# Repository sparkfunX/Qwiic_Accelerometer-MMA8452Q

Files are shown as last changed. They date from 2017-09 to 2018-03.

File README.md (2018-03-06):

View this project on [CADLAB.io](https://cadlab.io/node/733). 

Qwiic Accelerometer - MMA8452Q
========================================

Qwiic Accelerometer - MMA8452Q

[*SPX-14248*](https://www.sparkfun.com/products/14248)

The Qwiic Accelerometer makes it extremely easy to get playing with tilt, acceleration, and movement sensing. Plug a [Qwiic Shield](https://www.sparkfun.com/search/results?term=qwiic) onto your platform of choice, plug the Qwiic Accelerometer onto the shield and start sensing! 

The Qwiic Accelerometer - MMA8452Q is a smart low-power, three-axis, MEMS accelerometer with 12 bits of resolution. This accelerometer is packed with embedded functions with flexible user programmable options, configurable to two interrupt pins. Embedded interrupt functions allow for overall power savings relieving the host processor from continuously polling data.

The MMA8452Q has user selectable full scales of ±2g/±4g/±8g with high pass filtered data as well as non filtered data available real-time. The device can be configured to generate inertial wake-up interrupt signals from any combination of the configurable embedded functions allowing the MMA8452Q to monitor events and remain in a low power mode during periods of inactivity.

The [Qwiic system](http://www.sparkfun.com/qwiic) enables fast and solderless connection between popular platforms and various sensors and actuators. You can read more about the Qwiic system [here](http://www.sparkfun.com/qwiic). 

License Information
-------------------

This product is _**open source**_!

Please review the LICENSE.md file for license information.

If you have any questions or concerns on licensing, please contact techsupport@sparkfun.com.

Distributed as-is; no warranty is given.

- Your friends at SparkFun.

_<COLLABORATION CREDIT>_

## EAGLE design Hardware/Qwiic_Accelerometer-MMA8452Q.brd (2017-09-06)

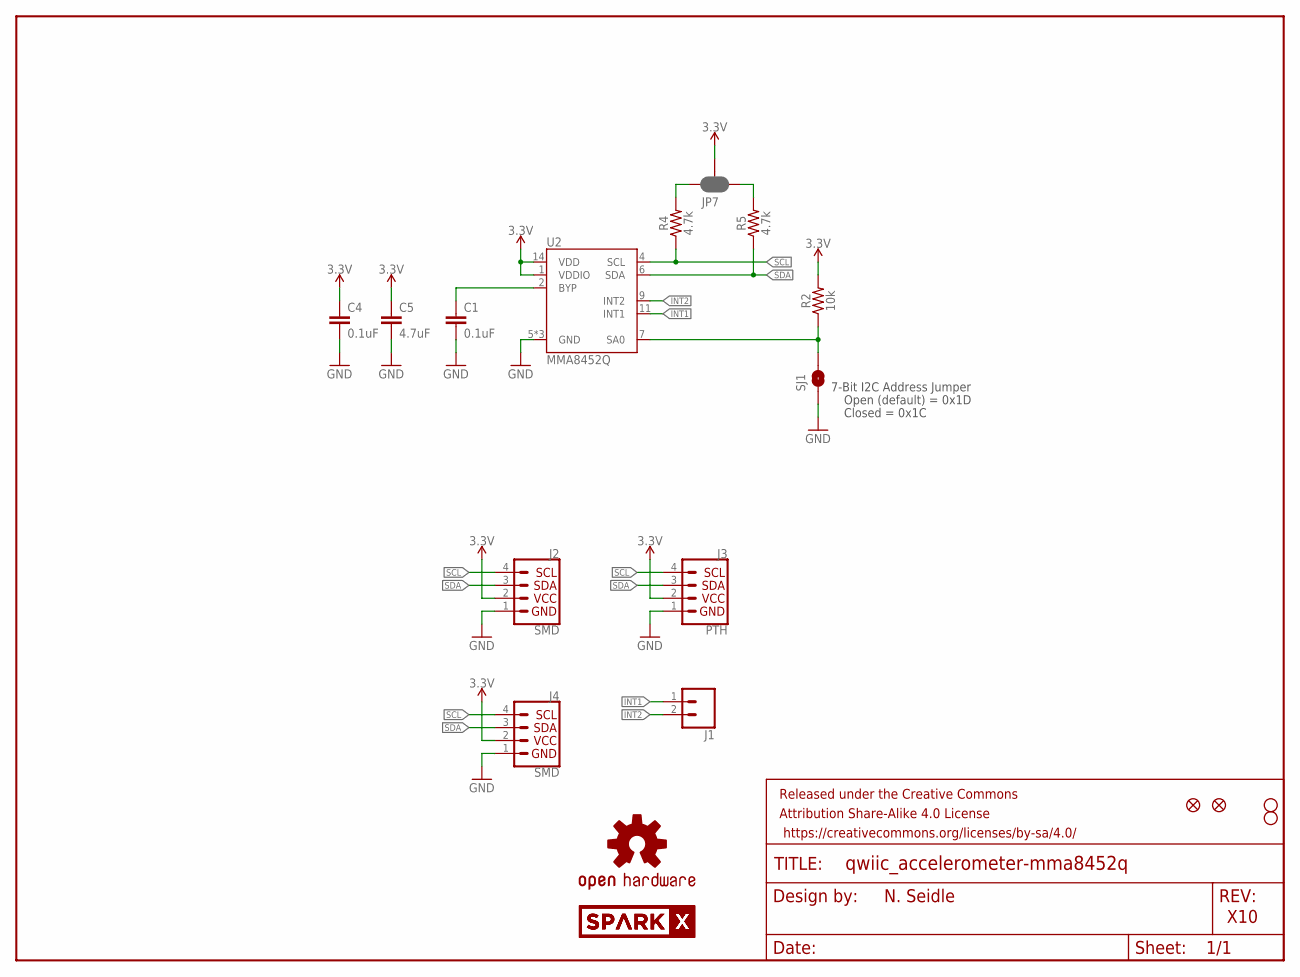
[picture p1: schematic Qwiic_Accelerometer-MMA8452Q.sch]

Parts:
C1, C4: 0.1uF; 0603
C5: 4.7uF; 0603
FRAME1: FRAME-LETTER; CREATIVE_COMMONS
J1: CONN_021X02_NO_SILK; 1X02_NO_SILK
J2, J4: SMD; 1X04_1MM_RA
J3: PTH; 1X04_NO_SILK
JP2, JP6: FIDUCIALUFIDUCIAL; MICRO-FIDUCIAL
JP3, JP4: STAND-OFF
JP7: JUMPER-SMT_3_2-NC_PASTE_SILK; SMT-JUMPER_3_2-NC_PASTE_SILK
LOGO1: OSHW-LOGOMINI; OSHW-LOGO-MINI
R2: 10k; 0603
R4, R5: 4.7k; 0603
SJ1: SOLDERJUMPERNO; SJ_2S-NO
U2: MMA8452Q; QFN-16_0.5MM
U$1, U$2: SPARKX-LOGO4; SPARKX-MEDIUM

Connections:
3.3V: C4.1, C5.1, J2.2 (VCC), J3.2 (VCC), J4.2 (VCC), JP7.2, R2.2, U2.1 (VDDIO), U2.14 (VDD)
BYP: C1.1, U2.2 (BYP)
GND: C1.2, C4.2, C5.2, J2.1 (GND), J3.1 (GND), J4.1 (GND), SJ1.1, U2.5 (GND), U2.10 (GND), U2.12 (GND)
INT1: J1.1, U2.11 (INT1)
INT2: J1.2, U2.9 (INT2)
unnamed: JP7.1, R5.2
unnamed: JP7.3, R4.2
SA0: R2.1, SJ1.2, U2.7 (SA0)
SCL: J2.4 (SCL), J3.4 (SCL), J4.4 (SCL), R4.1, U2.4 (SCL)
SDA: J2.3 (SDA), J3.3 (SDA), J4.3 (SDA), R5.1, U2.6 (SDA)

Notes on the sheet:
7-Bit I2C Address Jumper
Closed = 0x1C
Open (default) = 0x1D
N. Seidle
X10

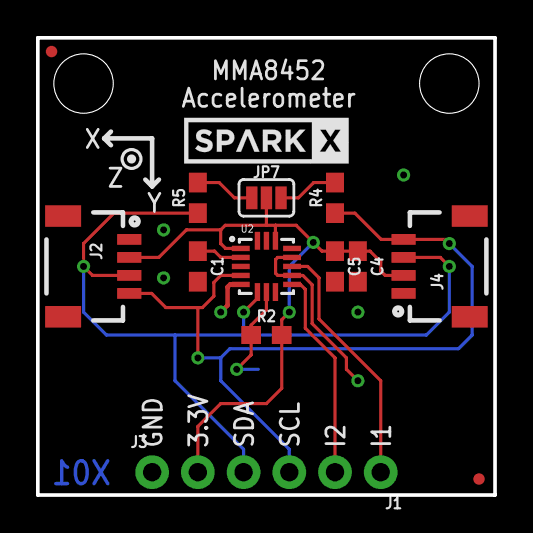
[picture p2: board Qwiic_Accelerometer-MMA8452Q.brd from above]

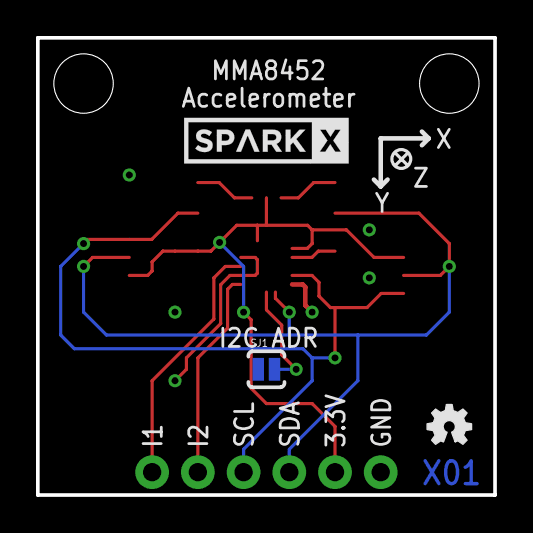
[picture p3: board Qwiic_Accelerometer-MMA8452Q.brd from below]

Board: 2 copper layers, 25.4 x 25.4 mm, 21 parts (3 on the bottom side), 10 nets.

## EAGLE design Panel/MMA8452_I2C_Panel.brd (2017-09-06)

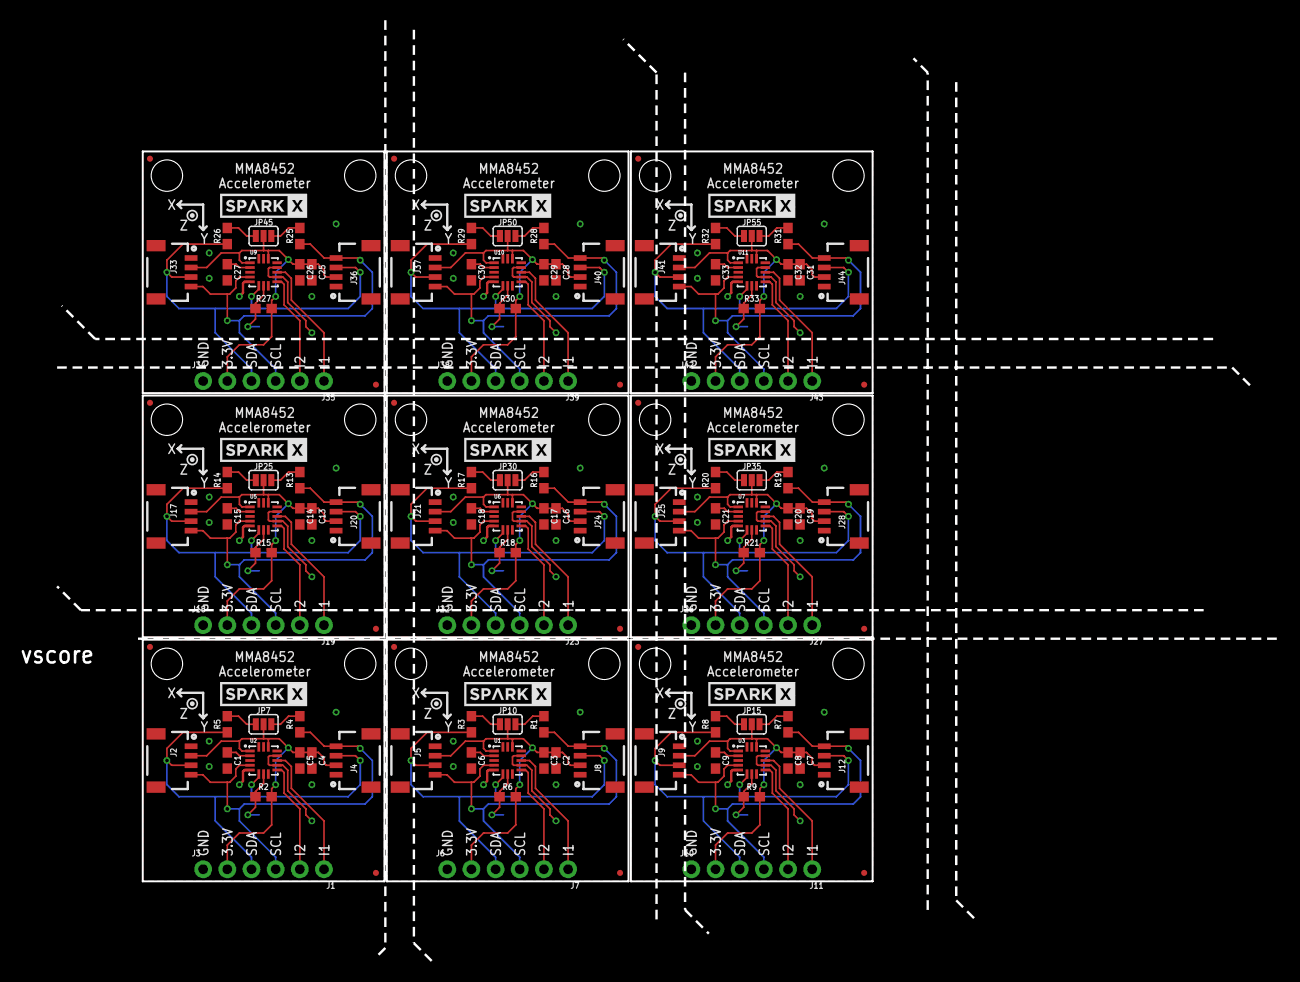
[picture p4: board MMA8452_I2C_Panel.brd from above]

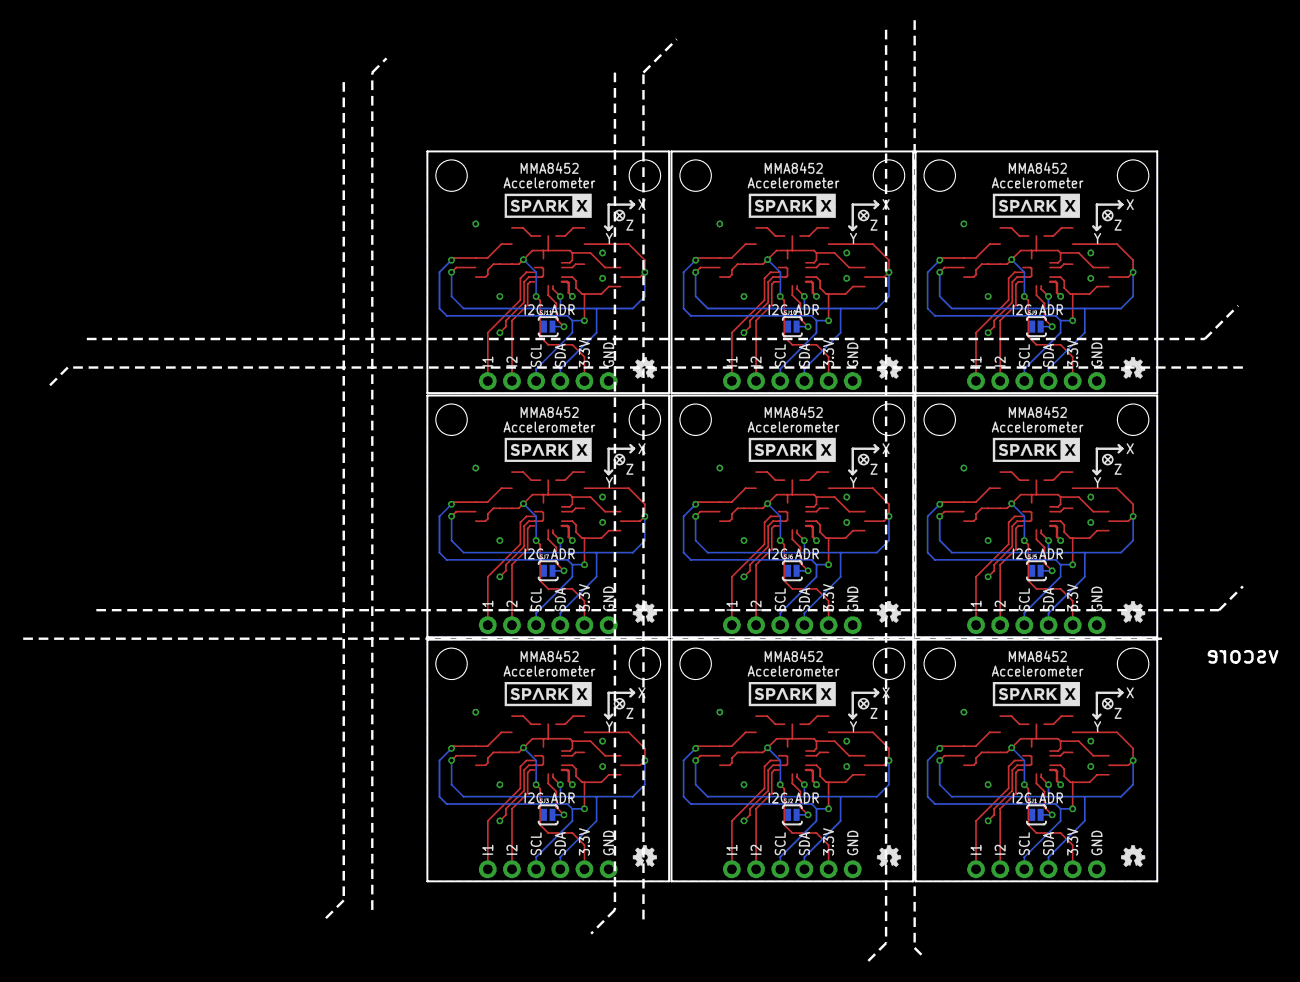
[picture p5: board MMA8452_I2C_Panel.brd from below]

Board: 2 copper layers, 128.5 x 99.0 mm, 180 parts (27 on the bottom side), 90 nets.

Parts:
C1, C2, C4, C6, C7, C9, C13, C15, C16, C18, C19, C21, C25, C27, C28, C30, C31, C33: 0.1uF; 0603
C3, C5, C8, C14, C17, C20, C26, C29, C32: 4.7uF; 0603
J1, J7, J11, J19, J23, J27, J35, J39, J43: 1X02_NO_SILK
J2, J4, J5, J8, J9, J12, J17, J20, J21, J24, J25, J28, J33, J36, J37, J40, J41, J44: SMD; 1X04_1MM_RA
J3, J6, J10, J18, J22, J26, J34, J38, J42: PTH; 1X04_NO_SILK
JP1, JP3, JP4, JP5, JP11, JP12, JP21, JP22, JP26, JP27, JP31, JP32, JP41, JP42, JP46, JP47, JP51, JP52: STAND-OFF
JP2, JP6, JP8, JP9, JP13, JP14, JP23, JP24, JP28, JP29, JP33, JP34, JP43, JP44, JP48, JP49, JP53, JP54: FIDUCIALUFIDUCIAL; MICRO-FIDUCIAL
JP7, JP10, JP15, JP25, JP30, JP35, JP45, JP50, JP55: SMT-JUMPER_3_2-NC_PASTE_SILK
LOGO1, LOGO2, LOGO3, LOGO5, LOGO6, LOGO7, LOGO9, LOGO10, LOGO11: OSHW-LOGOMINI; OSHW-LOGO-MINI
R1, R3, R4, R5, R7, R8, R13, R14, R16, R17, R19, R20, R25, R26, R28, R29, R31, R32: 4.7k; 0603
R2, R6, R9, R15, R18, R21, R27, R30, R33: 10k; 0603
SJ1, SJ2, SJ3, SJ5, SJ6, SJ7, SJ9, SJ10, SJ11: SJ_2S-NO
U1, U2, U3, U5, U6, U7, U9, U10, U11: MMA8452Q; QFN-16_0.5MM
U$1, U$2, U$3, U$4, U$5, U$6, U$9, U$10, U$11, U$12, U$13, U$14, U$17, U$18, U$19, U$20, U$21, U$22: SPARKX-LOGO4; SPARKX-MEDIUM

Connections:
3.3V: C4.1, C5.1, J2.2, J3.2, J4.2, JP7.2, R2.2, U2.1, U2.14
3.3V1: C2.1, C3.1, J5.2, J6.2, J8.2, JP10.2, R6.2, U1.1, U1.14
3.3V2: C7.1, C8.1, J9.2, J10.2, J12.2, JP15.2, R9.2, U3.1, U3.14
3.3V4: C13.1, C14.1, J17.2, J18.2, J20.2, JP25.2, R15.2, U5.1, U5.14
3.3V5: C16.1, C17.1, J21.2, J22.2, J24.2, JP30.2, R18.2, U6.1, U6.14
3.3V6: C19.1, C20.1, J25.2, J26.2, J28.2, JP35.2, R21.2, U7.1, U7.14
3.3V8: C25.1, C26.1, J33.2, J34.2, J36.2, JP45.2, R27.2, U9.1, U9.14
3.3V9: C28.1, C29.1, J37.2, J38.2, J40.2, JP50.2, R30.2, U10.1, U10.14
3.3V10: C31.1, C32.1, J41.2, J42.2, J44.2, JP55.2, R33.2, U11.1, U11.14
BYP: C1.1, U2.2
BYP1: C6.1, U1.2
BYP2: C9.1, U3.2
BYP4: C15.1, U5.2
BYP5: C18.1, U6.2
BYP6: C21.1, U7.2
BYP8: C27.1, U9.2
BYP9: C30.1, U10.2
BYP10: C33.1, U11.2
GND: C1.2, C4.2, C5.2, J2.1, J3.1, J4.1, SJ1.1, U2.5, U2.10, U2.12
GND1: C2.2, C3.2, C6.2, J5.1, J6.1, J8.1, SJ2.1, U1.5, U1.10, U1.12
GND2: C7.2, C8.2, C9.2, J9.1, J10.1, J12.1, SJ3.1, U3.5, U3.10, U3.12
GND4: C13.2, C14.2, C15.2, J17.1, J18.1, J20.1, SJ5.1, U5.5, U5.10, U5.12
GND5: C16.2, C17.2, C18.2, J21.1, J22.1, J24.1, SJ6.1, U6.5, U6.10, U6.12
GND6: C19.2, C20.2, C21.2, J25.1, J26.1, J28.1, SJ7.1, U7.5, U7.10, U7.12
GND8: C25.2, C26.2, C27.2, J33.1, J34.1, J36.1, SJ9.1, U9.5, U9.10, U9.12
GND9: C28.2, C29.2, C30.2, J37.1, J38.1, J40.1, SJ10.1, U10.5, U10.10, U10.12
GND10: C31.2, C32.2, C33.2, J41.1, J42.1, J44.1, SJ11.1, U11.5, U11.10, U11.12
INT1: J1.1, U2.11
INT2: J1.2, U2.9
INT3: J7.2, U1.9
INT4: J7.1, U1.11
INT5: J11.2, U3.9
INT6: J11.1, U3.11
INT9: J19.2, U5.9
INT10: J19.1, U5.11
INT11: J23.2, U6.9
INT12: J23.1, U6.11
INT13: J27.2, U7.9
INT14: J27.1, U7.11
INT17: J35.2, U9.9
INT18: J35.1, U9.11
INT19: J39.2, U10.9
INT20: J39.1, U10.11
INT21: J43.2, U11.9
INT22: J43.1, U11.11
unnamed: JP7.1, R5.2
unnamed: JP7.3, R4.2
unnamed: JP10.1, R3.2
unnamed: JP10.3, R1.2
unnamed: JP15.1, R8.2
unnamed: JP15.3, R7.2
unnamed: JP25.1, R14.2
unnamed: JP25.3, R13.2
unnamed: JP30.1, R17.2
unnamed: JP30.3, R16.2
unnamed: JP35.1, R20.2
unnamed: JP35.3, R19.2
unnamed: JP45.1, R26.2
unnamed: JP45.3, R25.2
unnamed: JP50.1, R29.2
unnamed: JP50.3, R28.2
unnamed: JP55.1, R32.2
unnamed: JP55.3, R31.2
SA0: R2.1, SJ1.2, U2.7
SA1: R6.1, SJ2.2, U1.7
SA2: R9.1, SJ3.2, U3.7
SA4: R15.1, SJ5.2, U5.7
SA5: R18.1, SJ6.2, U6.7
SA6: R21.1, SJ7.2, U7.7
SA8: R27.1, SJ9.2, U9.7
SA9: R30.1, SJ10.2, U10.7
SA10: R33.1, SJ11.2, U11.7
SCL: J2.4, J3.4, J4.4, R4.1, U2.4
SCL1: J5.4, J6.4, J8.4, R1.1, U1.4
SCL2: J9.4, J10.4, J12.4, R7.1, U3.4
SCL4: J17.4, J18.4, J20.4, R13.1, U5.4
SCL5: J21.4, J22.4, J24.4, R16.1, U6.4
SCL6: J25.4, J26.4, J28.4, R19.1, U7.4
SCL8: J33.4, J34.4, J36.4, R25.1, U9.4
SCL9: J37.4, J38.4, J40.4, R28.1, U10.4
SCL10: J41.4, J42.4, J44.4, R31.1, U11.4
SDA: J2.3, J3.3, J4.3, R5.1, U2.6
SDA1: J5.3, J6.3, J8.3, R3.1, U1.6
SDA2: J9.3, J10.3, J12.3, R8.1, U3.6
SDA4: J17.3, J18.3, J20.3, R14.1, U5.6
SDA5: J21.3, J22.3, J24.3, R17.1, U6.6
SDA6: J25.3, J26.3, J28.3, R20.1, U7.6
SDA8: J33.3, J34.3, J36.3, R26.1, U9.6
SDA9: J37.3, J38.3, J40.3, R29.1, U10.6
SDA10: J41.3, J42.3, J44.3, R32.1, U11.6

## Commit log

2017-03-08 Added a GND via. Created 3mm spaced panel.
    [MMA8452_I2C_Panel.GBL, MMA8452_I2C_Panel.GBO, MMA8452_I2C_Panel.GBS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]
2017-03-31 Adding berbers
    Note: added new berbers for stencil but this order still did not line
    up with 2mil gaps.
    [MMA8452_I2C_Panel.GBL, MMA8452_I2C_Panel.GBO, MMA8452_I2C_Panel.GBS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]
2017-03-31 File rename
    [Qwiic_Accelerometer-MMA8452Q.brd, Qwiic_Accelerometer-MMA8452Q.sch]
2017-09-06 Reducing panel size to 3x3
    [MMA8452_I2C_Panel.GBL, MMA8452_I2C_Panel.GBO, MMA8452_I2C_Panel.GBS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]

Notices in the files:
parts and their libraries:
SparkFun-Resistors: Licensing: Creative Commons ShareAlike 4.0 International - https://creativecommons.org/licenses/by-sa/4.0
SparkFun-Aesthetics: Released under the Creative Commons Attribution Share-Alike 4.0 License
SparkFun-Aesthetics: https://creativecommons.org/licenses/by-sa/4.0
